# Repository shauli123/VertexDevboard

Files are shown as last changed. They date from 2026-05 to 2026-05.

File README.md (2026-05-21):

# Vertex Dev-board
A simple RP2040 based dev-board with:
- USB-C Connection
- Flash Memory
- Crystal Oscillator
- Boot Button

Schema:
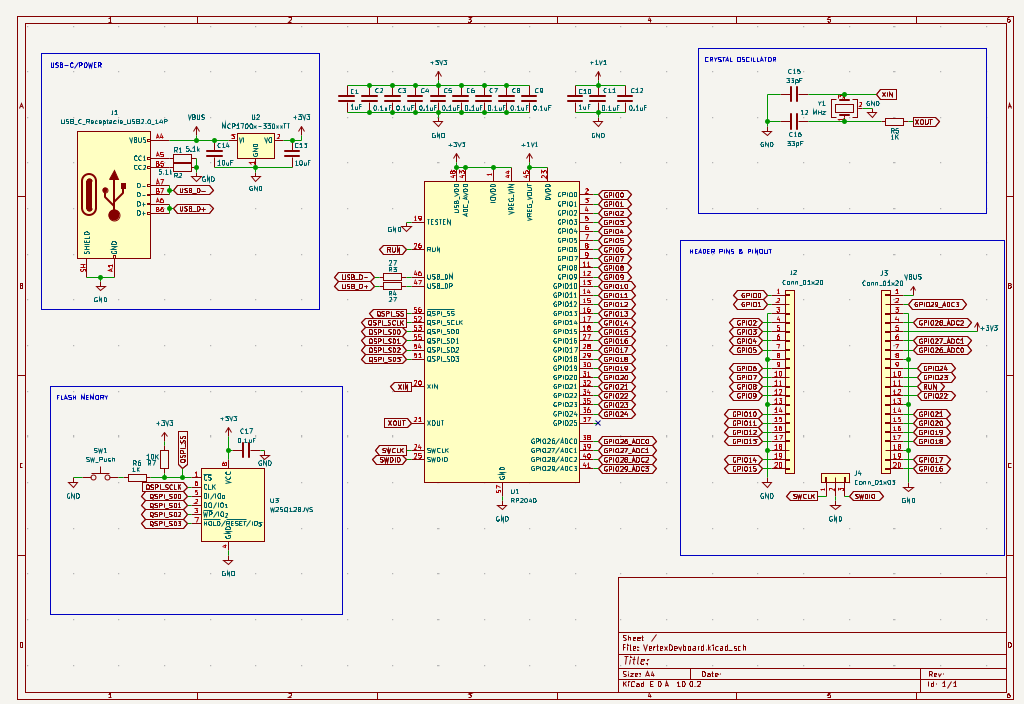
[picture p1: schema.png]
the schema


The Pinout:
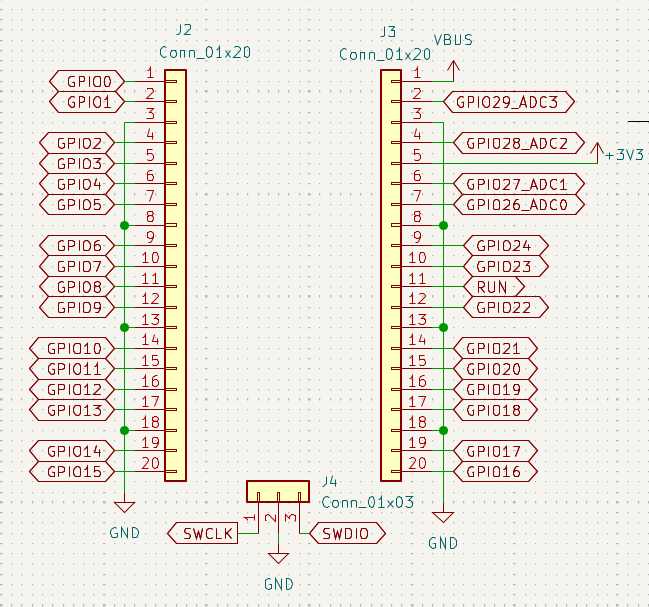
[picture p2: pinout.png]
pinout


The PCB Design:
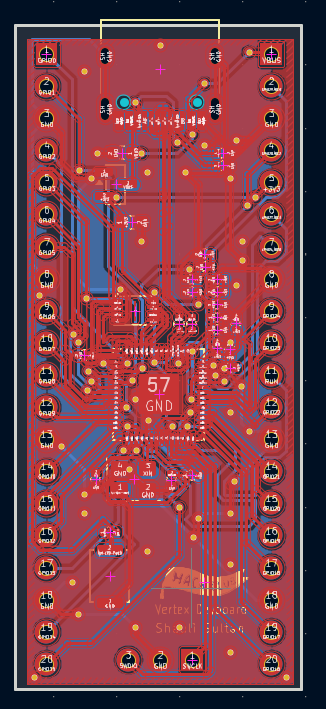
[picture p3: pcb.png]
pcb


A 3D Render:
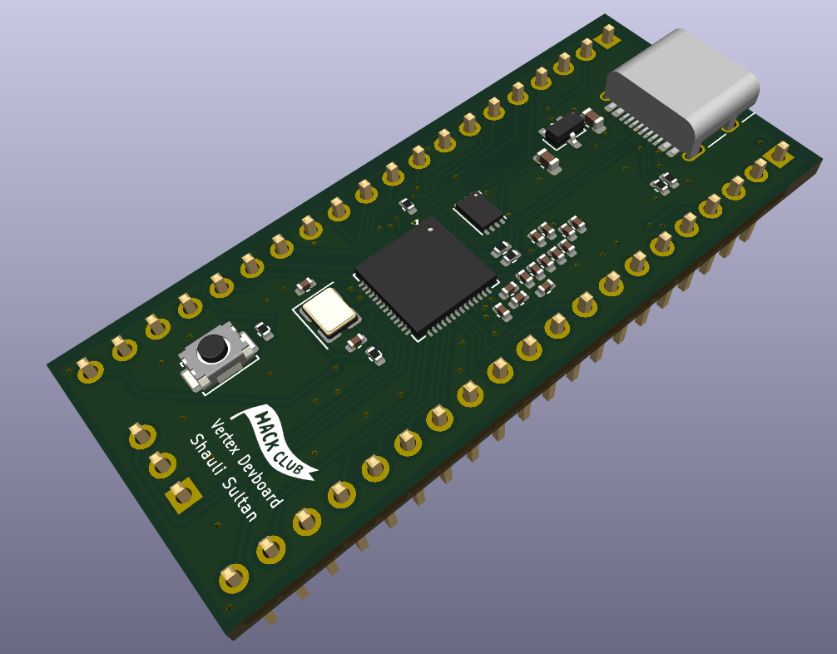
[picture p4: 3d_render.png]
3d render


I've always wanted to understand how a devboard works
so i made one myself!
in the way i learnt:
- Why stable power is needed.
- how usb-c even works.
- How SPI & Quad-SPI works.
- What is a flash memory.
- Why do we need a clock(crystal oscillator).
- Why do we need a boot button.
- How to build a schema in kicad.
- How to build a pcb in kicad.
- What is a via.
- What is a copper filled zone.
- What is a diff pair.
- How to pass a DRC.
- How to fabricate.

It was a good journey and if i will have some time maybe i will work on a V2 with a RST Button, Wifi & BLE

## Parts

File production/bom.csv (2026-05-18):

Designator | Footprint | Quantity | Value | LCSC Part #
C1, C10 | 0402 | 2 | 1uF
C11, C12, C17, C2, C3, C4, C5, C6, C7, C8, C9 | 0402 | 11 | 0.1uF
C13, C14 | 0603 | 2 | 10uF
C15, C16 | 0402 | 2 | 33pF
J1 | USB_C_Receptacle_HRO_TYPE-C-31-M-12 | 1 | USB_C_Receptacle_USB2.0_14P
J2, J3 | PinHeader_1x20_P2.54mm_Vertical | 2 | Conn_01x20
J4 | PinHeader_1x03_P2.54mm_Vertical | 1 | Conn_01x03
R1, R2 | 0402 | 2 | 5.1k
R3, R4 | 0402 | 2 | 27
R5, R6 | 0402 | 2 | 1K
R7 | 0402 | 1 | 10K
SW1 | SW_Push_SPST_NO_Alps_SKRK | 1 | SW_Push
U1 | QFN-56-1EP_7x7mm_P0.4mm_EP3.2x3.2mm | 1 | RP2040
U2 | SOT-23 | 1 | MCP1700x-330xxTT
U3 | Winbond_USON-8-1EP_3x2mm_P0.5mm_EP0.2x1.6mm | 1 | W25Q128JVS
Y1 | Crystal_SMD_3225-4Pin_3.2x2.5mm | 1 | 12 MHz

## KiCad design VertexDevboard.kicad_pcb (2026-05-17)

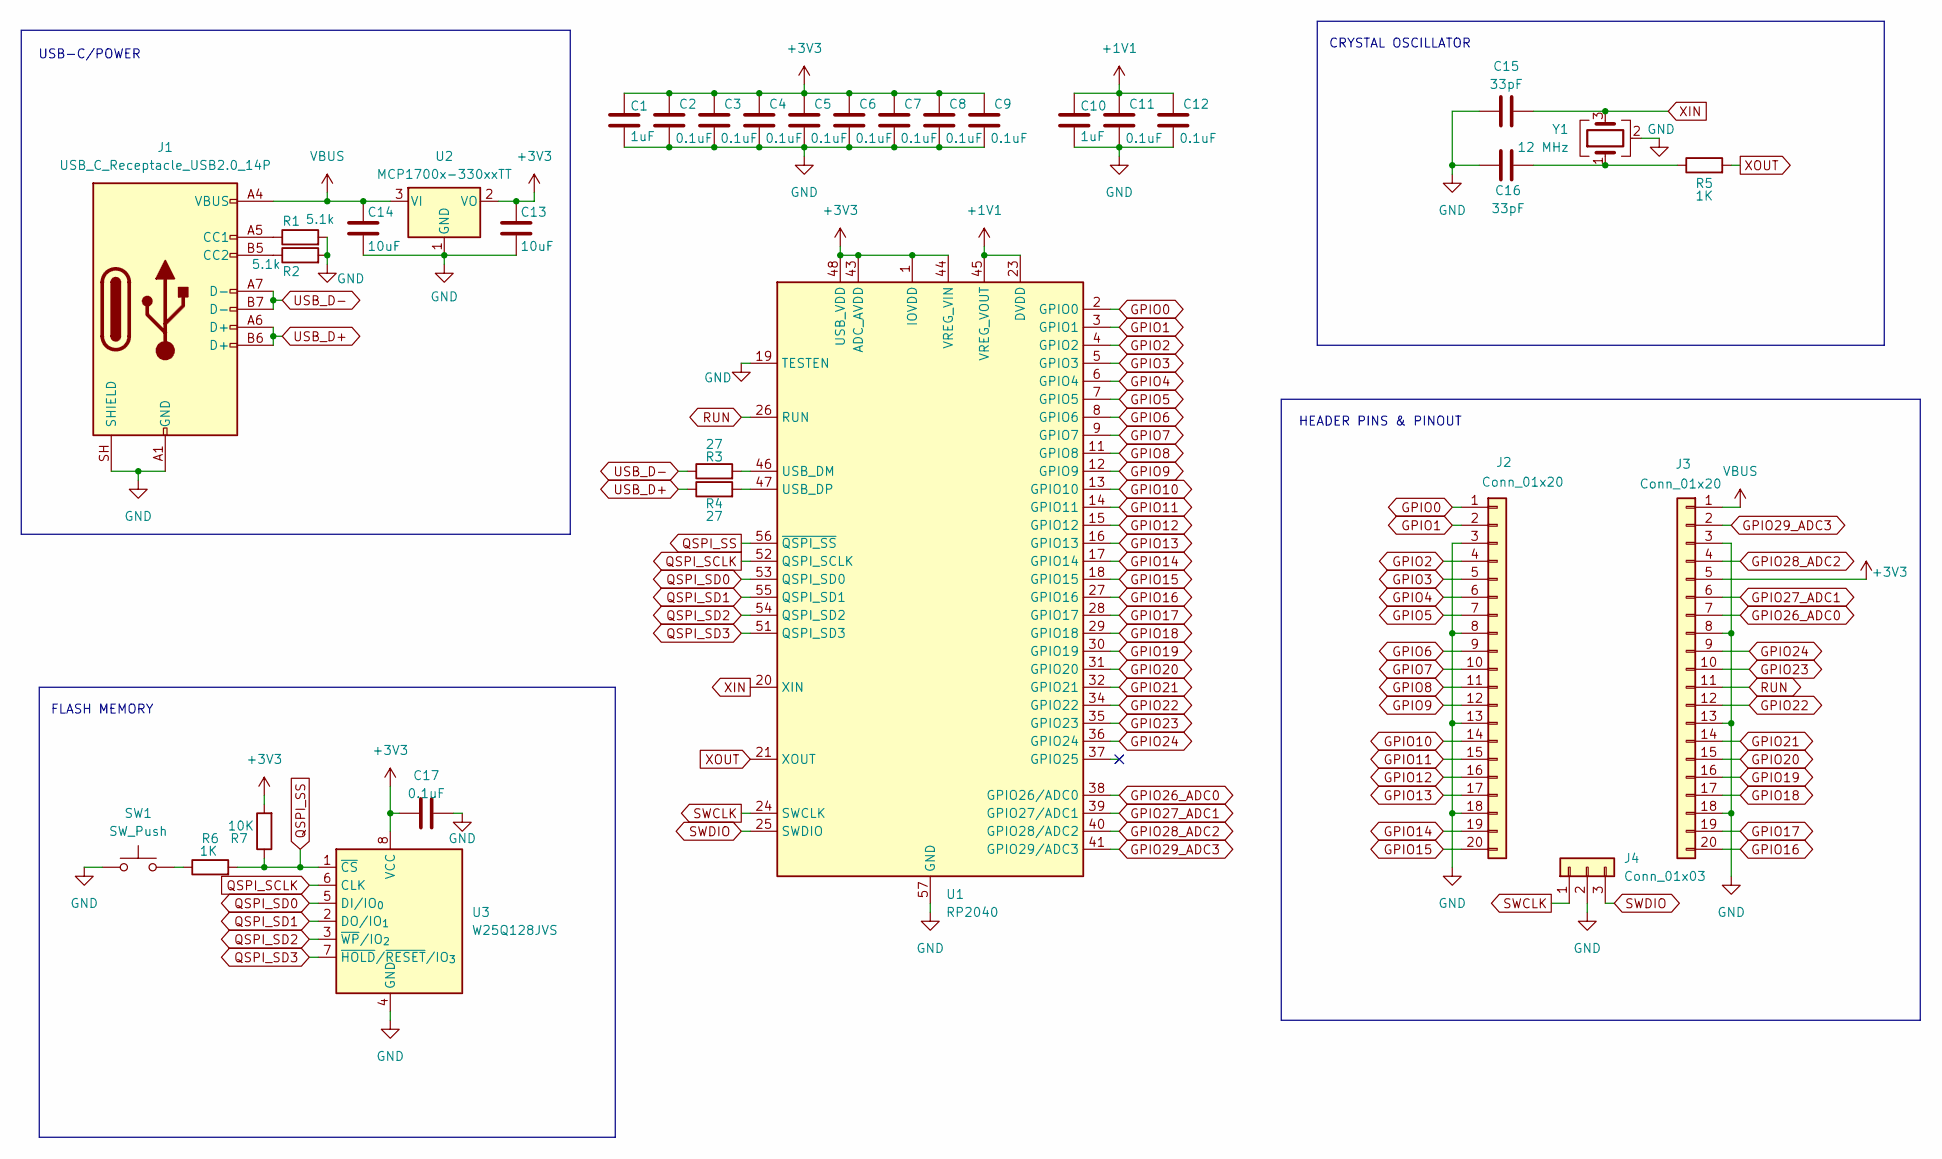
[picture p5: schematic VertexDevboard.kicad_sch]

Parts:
C1, C10: 1uF; C_0402_1005Metric
C2, C3, C4, C5, C6, C7, C8, C9, C11, C12, C17: 0.1uF; C_0402_1005Metric
C13, C14: 10uF; C_0603_1608Metric
C15, C16: 33pF; C_0402_1005Metric
J1: USB_C_Receptacle_USB2.0_14P; USB_C_Receptacle_HRO_TYPE-C-31-M-12
J2, J3: Conn_01x20; PinHeader_1x20_P2.54mm_Vertical
J4: Conn_01x03; PinHeader_1x03_P2.54mm_Vertical
R1, R2: 5.1k; R_0402_1005Metric
R3, R4: 27; R_0402_1005Metric
R5, R6: 1K; R_0402_1005Metric
R7: 10K; R_0402_1005Metric
SW1: SW_Push; SW_Push_SPST_NO_Alps_SKRK
U1: RP2040; QFN-56-1EP_7x7mm_P0.4mm_EP3.2x3.2mm
U2: MCP1700x-330xxTT; SOT-23
U3: W25Q128JVS; Winbond_USON-8-1EP_3x2mm_P0.5mm_EP0.2x1.6mm
Y1: 12 MHz; Crystal_SMD_3225-4Pin_3.2x2.5mm

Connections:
+1V1: C10.1, C11.1, C12.1, U1.23 (DVDD), U1.45 (VREG_VOUT), U1.50 (DVDD)
+3V3: C1.1, C2.1, C3.1, C4.1, C5.1, C6.1, C7.1, C8.1, C9.1, C13.1, C17.2, J3.5, R7.2, U1.1 (IOVDD), U1.10 (IOVDD), U1.22 (IOVDD), U1.33 (IOVDD), U1.42 (IOVDD), U1.43 (ADC_AVDD), U1.44 (VREG_VIN), U1.48 (USB_VDD), U1.49 (IOVDD), U2.2 (VO), U3.8 (VCC)
GND: C1.2, C2.2, C3.2, C4.2, C5.2, C6.2, C7.2, C8.2, C9.2, C10.2, C11.2, C12.2, C13.2, C14.2, C15.1, C16.1, C17.1, J1.A1 (GND), J1.A12 (GND), J1.B1 (GND), J1.B12 (GND), J1.SH (SHIELD), J2.3, J2.8, J2.13, J2.18, J3.3, J3.8, J3.13, J3.18, J4.2, R1.2, R2.2, SW1.1, U1.19 (TESTEN), U1.57 (GND), U2.1 (GND), U3.4 (GND), Y1.2 (G), Y1.4 (G)
GPIO0: J2.1, U1.2 (GPIO0)
GPIO1: J2.2, U1.3 (GPIO1)
GPIO2: J2.4, U1.4 (GPIO2)
GPIO3: J2.5, U1.5 (GPIO3)
GPIO4: J2.6, U1.6 (GPIO4)
GPIO5: J2.7, U1.7 (GPIO5)
GPIO6: J2.9, U1.8 (GPIO6)
GPIO7: J2.10, U1.9 (GPIO7)
GPIO8: J2.11, U1.11 (GPIO8)
GPIO9: J2.12, U1.12 (GPIO9)
GPIO10: J2.14, U1.13 (GPIO10)
GPIO11: J2.15, U1.14 (GPIO11)
GPIO12: J2.16, U1.15 (GPIO12)
GPIO13: J2.17, U1.16 (GPIO13)
GPIO14: J2.19, U1.17 (GPIO14)
GPIO15: J2.20, U1.18 (GPIO15)
GPIO16: J3.20, U1.27 (GPIO16)
GPIO17: J3.19, U1.28 (GPIO17)
GPIO18: J3.17, U1.29 (GPIO18)
GPIO19: J3.16, U1.30 (GPIO19)
GPIO20: J3.15, U1.31 (GPIO20)
GPIO21: J3.14, U1.32 (GPIO21)
GPIO22: J3.12, U1.34 (GPIO22)
GPIO23: J3.10, U1.35 (GPIO23)
GPIO24: J3.9, U1.36 (GPIO24)
GPIO26_ADC0: J3.7, U1.38 (GPIO26/ADC0)
GPIO27_ADC1: J3.6, U1.39 (GPIO27/ADC1)
GPIO28_ADC2: J3.4, U1.40 (GPIO28/ADC2)
GPIO29_ADC3: J3.2, U1.41 (GPIO29/ADC3)
unnamed: C16.2, R5.1, Y1.1
unnamed: J1.A5 (CC1), R1.1
unnamed: J1.B5 (CC2), R2.1
unnamed: R6.1, SW1.2
unnamed: R3.2, U1.46 (USB_DM)
unnamed: R4.2, U1.47 (USB_DP)
QSPI_SCLK: U1.52 (QSPI_SCLK), U3.6 (CLK)
QSPI_SD0: U1.53 (QSPI_SD0), U3.5 (DI/IO_{0})
QSPI_SD1: U1.55 (QSPI_SD1), U3.2 (DO/IO_{1})
QSPI_SD2: U1.54 (QSPI_SD2), U3.3 (~WP/IO_{2})
QSPI_SD3: U1.51 (QSPI_SD3), U3.7 (~HOLD/~RESET/IO_{3})
QSPI_SS: R6.2, R7.1, U1.56 (~QSPI_SS), U3.1 (~CS)
RUN: J3.11, U1.26 (RUN)
SWCLK: J4.1, U1.24 (SWCLK)
SWDIO: J4.3, U1.25 (SWDIO)
USB_D+: J1.A6 (D+), J1.B6 (D+), R4.1
USB_D-: J1.A7 (D-), J1.B7 (D-), R3.1
VBUS: C14.1, J1.A4 (VBUS), J1.A9 (VBUS), J1.B4 (VBUS), J1.B9 (VBUS), J3.1, U2.3 (VI)
XIN: C15.2, U1.20 (XIN), Y1.3
XOUT: R5.2, U1.21 (XOUT)

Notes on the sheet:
USB-C/POWER
FLASH MEMORY
CRYSTAL OSCILLATOR
HEADER PINS & PINOUT

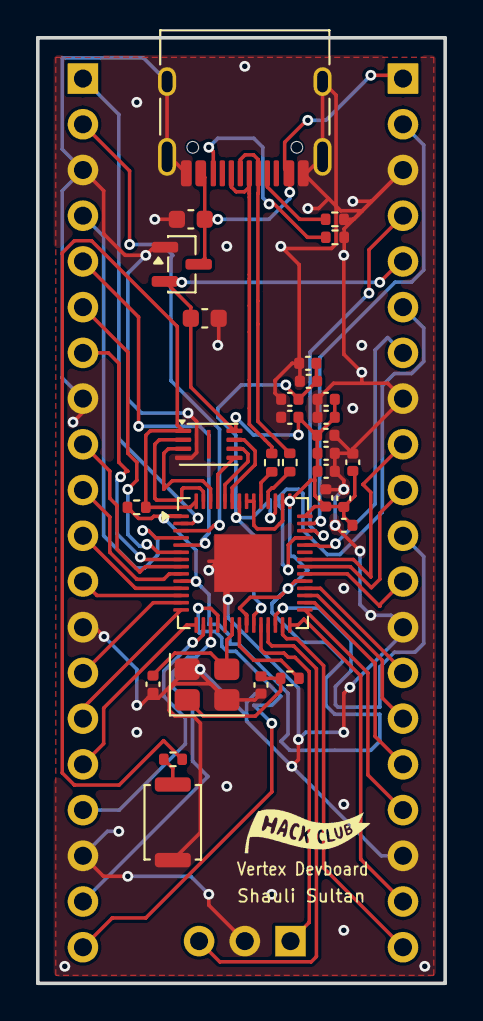
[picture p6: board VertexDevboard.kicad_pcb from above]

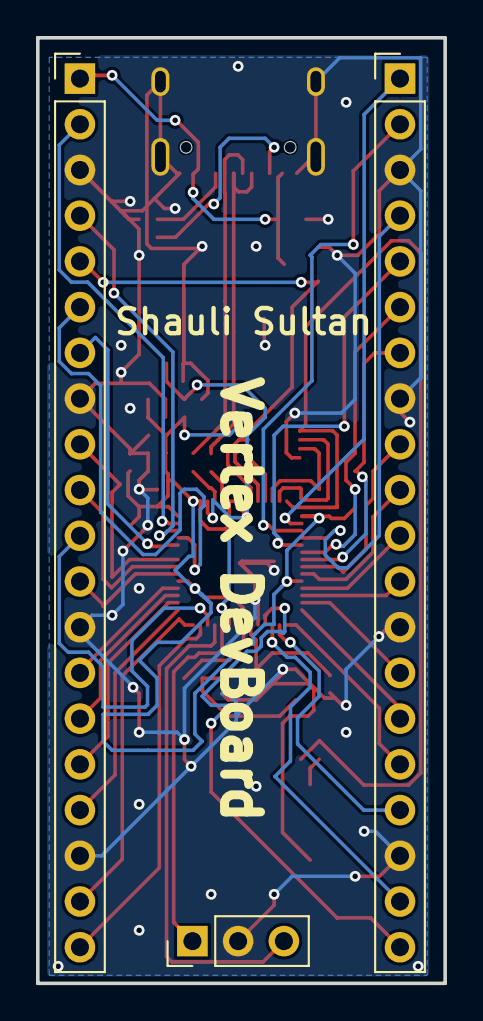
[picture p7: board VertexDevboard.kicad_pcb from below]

Board: 2 copper layers, 22.6 x 52.5 mm, 33 parts (3 on the bottom side), 52 nets.

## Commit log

2026-05-17 pbc 1
    [VertexDevboard.kicad_pcb, VertexDevboard.kicad_sch]
2026-05-17 DRC OK
    [VertexDevboard.kicad_pcb]
2026-05-17 Before fabric
    [VertexDevboard.kicad_pcb]
2026-05-17 Before fabric 0 DRC Erros
    [VertexDevboard.kicad_pcb]
2026-05-18 first prod
    [bom.csv, designators.csv, positions.csv]
